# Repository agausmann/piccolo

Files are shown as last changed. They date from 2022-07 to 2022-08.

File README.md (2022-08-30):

# piccolo

A Raspberry Pi Pico clone with a USB-C port.

It's _\[current year\]_. Micro-USB is old news. But board designers are, for
some reason, still using it. I dunno, it might be a little cheaper/simpler.
Maybe you don't _technically_ need USB-C anway if you're not using USB 3.0.
But, in my experience, USB-C is just so much better; there is hardly any
reason to not use it.

## License

In the spirit of the original Pico design:

These design files are made available openly, with no limitations.

Permission to use, copy, modify, and/or distribute this design for
any purpose with or without fee is hereby granted.

THE DESIGN IS PROVIDED "AS IS" AND THE AUTHOR DISCLAIMS ALL WARRANTIES
WITH REGARD TO THIS DESIGN INCLUDING ALL IMPLIED WARRANTIES OF
MERCHANTABILITY AND FITNESS. IN NO EVENT SHALL THE AUTHOR BE LIABLE
FOR ANY SPECIAL, DIRECT, INDIRECT, OR CONSEQUENTIAL DAMAGES OR ANY
DAMAGES WHATSOEVER RESULTING FROM LOSS OF USE, DATA OR PROFITS, WHETHER
IN AN ACTION OF CONTRACT, NEGLIGENCE OR OTHER TORTIOUS ACTION, ARISING
OUT OF OR IN CONNECTION WITH THE USE OR PERFORMANCE OF THIS DESIGN.

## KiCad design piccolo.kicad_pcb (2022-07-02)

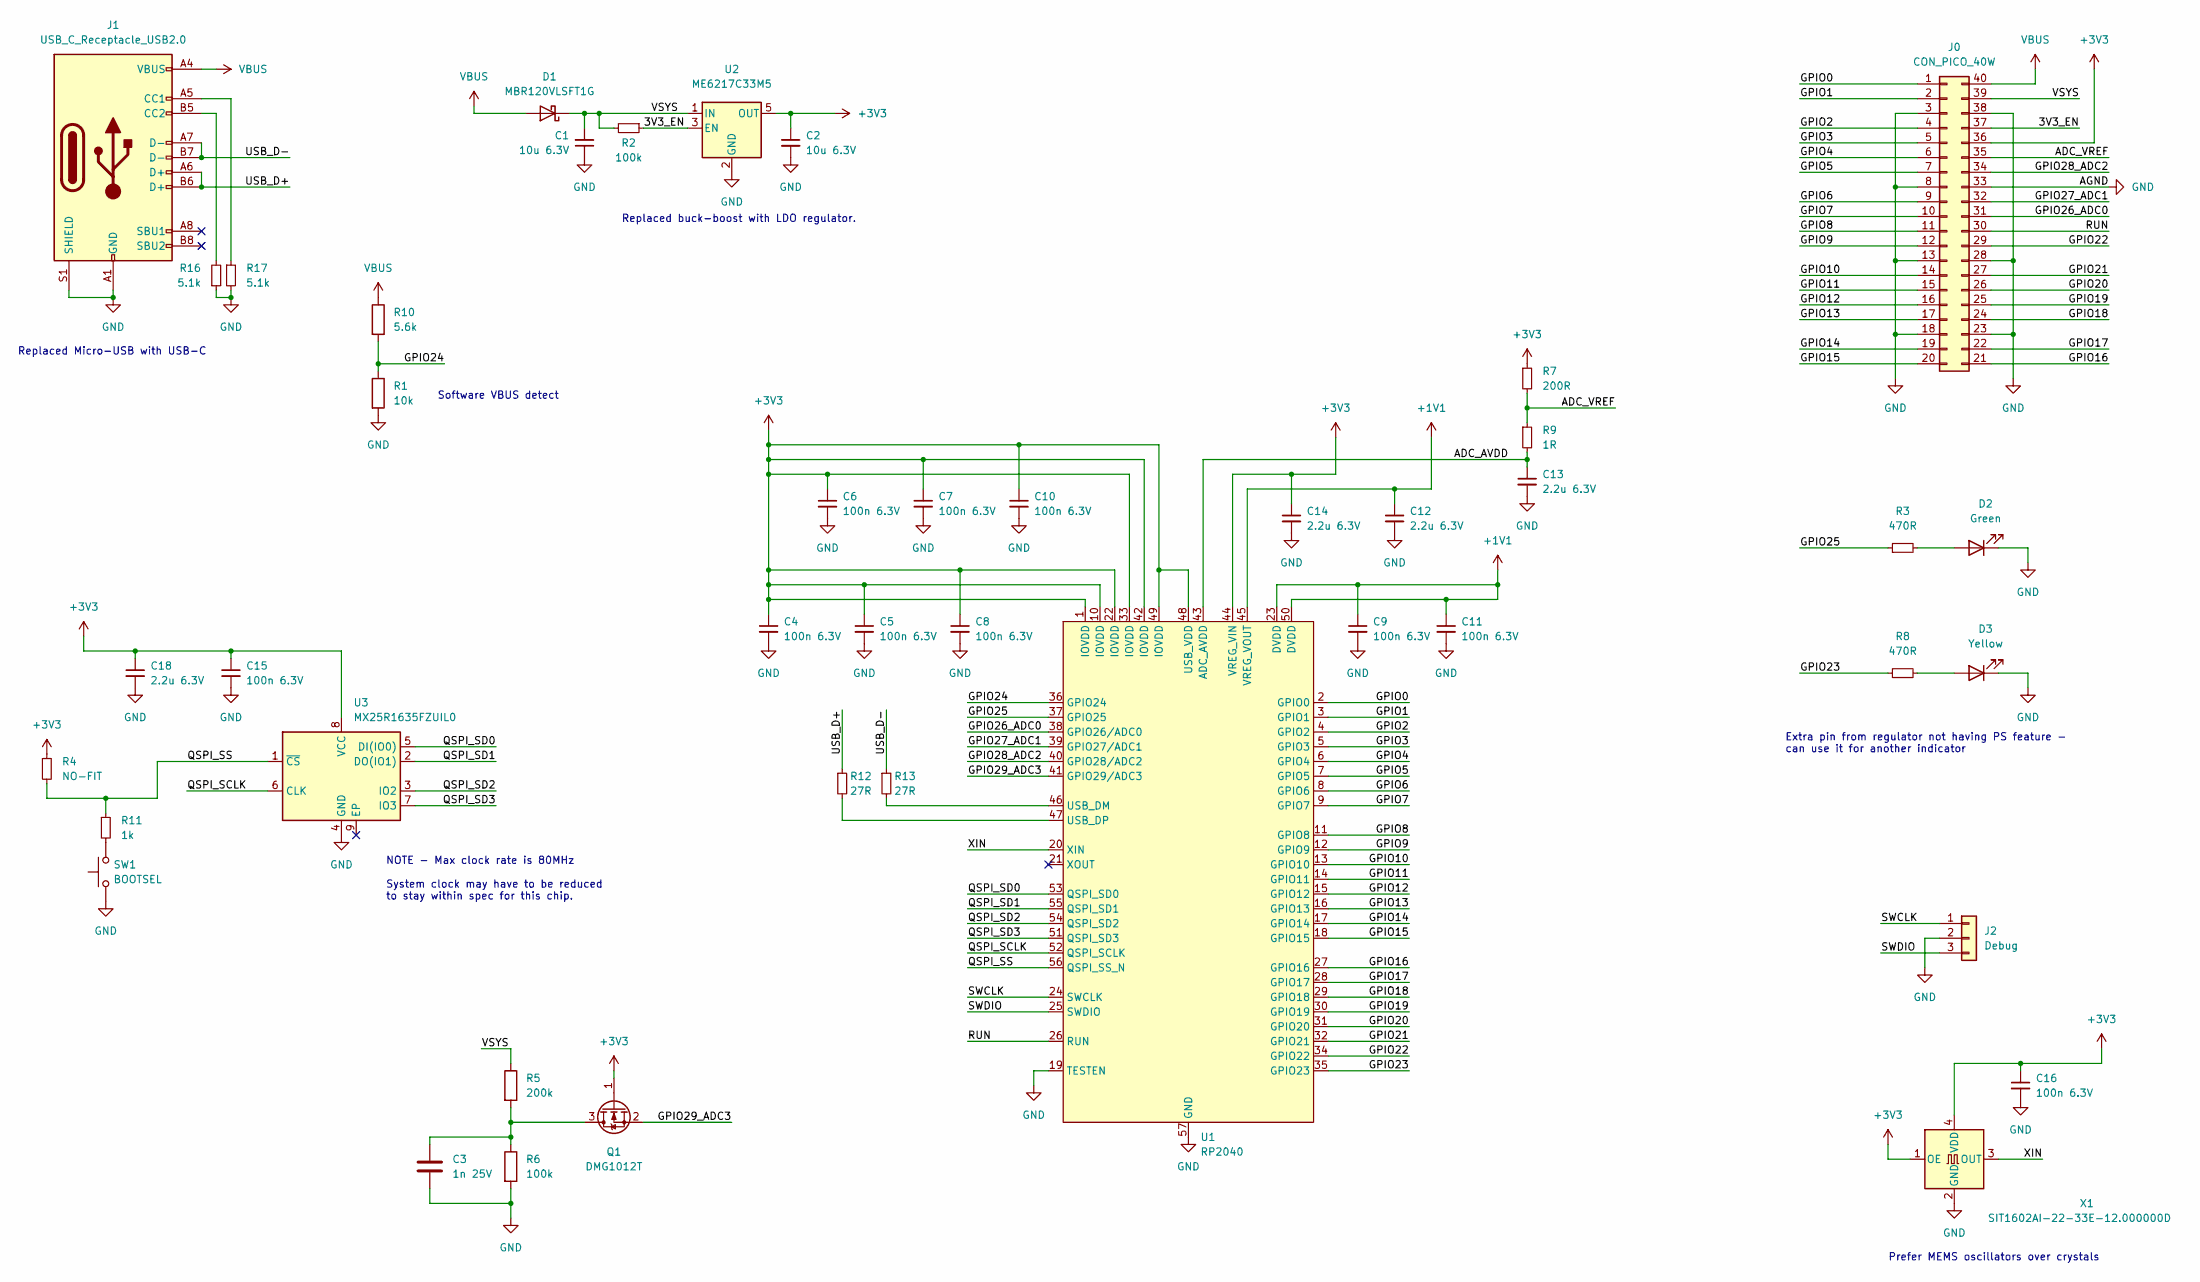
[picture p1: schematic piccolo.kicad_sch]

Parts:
C1, C2: 10u 6.3V; C_0805_2012Metric; LCSC C440198
C3: 1n 25V; C_0402_1005Metric; LCSC C66942
C4, C5, C6, C7, C8, C9, C10, C11, C15, C16: 100n 6.3V; C_0201_0603Metric; LCSC C160831
C12, C13, C14, C18: 2.2u 6.3V; C_0402_1005Metric; LCSC C12530
D1: MBR120VLSFT1G; D_SOD-123F; LCSC C123070
D2: Green; LED_0603_1608Metric; LCSC C72043
D3: Yellow; LED_0603_1608Metric; LCSC C72043
J0: CON_PICO_40W; RaspberryPi_Pico_OutlineAndPads
J1: USB_C_Receptacle_USB2.0; USB_C_Receptacle_HRO_TYPE-C-31-M-12; LCSC C165948
J2: Debug; PinHeader_1x03_P2.54mm_Vertical
Q1: DMG1012T; SOT-523; LCSC C2830301
R1: 10k; R_0402_1005Metric; LCSC C25744
R2, R6: 100k; R_0402_1005Metric; LCSC C25741
R3, R8: 470R; R_0402_1005Metric; LCSC C25117
R4: NO-FIT; R_0402_1005Metric
R5: 200k; R_0402_1005Metric; LCSC C25764
R7: 200R; R_0603_1608Metric; LCSC C25087
R9: 1R; R_0402_1005Metric; LCSC C25086
R10: 5.6k; R_0402_1005Metric; LCSC C25908
R11: 1k; R_0402_1005Metric; LCSC C11702
R12, R13: 27R; R_0201_0603Metric; LCSC C25100
R16, R17: 5.1k; R_0402_1005Metric; LCSC C25905
SW1: BOOTSEL; SW_Push_1P1T_NO_Vertical_Wuerth_434133025816
U1: RP2040; RP2040_QFN-56-1EP_7x7mm_P0.4mm_EP3.2x3.2mm_ThermalVias; LCSC C2040
U2: ME6217C33M5; SOT-23-5; LCSC C427602
U3: MX25R1635FZUIL0; USON-8-1EP_3x2mm_P0.5mm_EP0.2x1.6mm; LCSC C152595
X1: SIT1602AI-22-33E-12.000000D; SiT1602xx-2_3.2x2.5mm; LCSC C29752

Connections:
+1V1: C9.1, C11.1, C12.1, U1.23 (DVDD), U1.45 (VREG_VOUT), U1.50 (DVDD)
+3V3: C2.1, C4.1, C5.1, C6.1, C7.1, C8.1, C10.1, C14.1, C15.1, C16.1, C18.1, J0.36, Q1.1 (G), R4.1, R7.1, U1.1 (IOVDD), U1.10 (IOVDD), U1.22 (IOVDD), U1.33 (IOVDD), U1.42 (IOVDD), U1.44 (VREG_VIN), U1.48 (USB_VDD), U1.49 (IOVDD), U2.5 (OUT), U3.8 (VCC), X1.1 (OE), X1.4 (VDD)
/3V3_EN: J0.37, R2.1, U2.3 (EN)
/ADC_AVDD: C13.1, R9.2, U1.43 (ADC_AVDD)
/ADC_VREF: J0.35, R7.2, R9.1
/GPIO0: J0.1, U1.2 (GPIO0)
/GPIO1: J0.2, U1.3 (GPIO1)
/GPIO2: J0.4, U1.4 (GPIO2)
/GPIO3: J0.5, U1.5 (GPIO3)
/GPIO4: J0.6, U1.6 (GPIO4)
/GPIO5: J0.7, U1.7 (GPIO5)
/GPIO6: J0.9, U1.8 (GPIO6)
/GPIO7: J0.10, U1.9 (GPIO7)
/GPIO8: J0.11, U1.11 (GPIO8)
/GPIO9: J0.12, U1.12 (GPIO9)
/GPIO10: J0.14, U1.13 (GPIO10)
/GPIO11: J0.15, U1.14 (GPIO11)
/GPIO12: J0.16, U1.15 (GPIO12)
/GPIO13: J0.17, U1.16 (GPIO13)
/GPIO14: J0.19, U1.17 (GPIO14)
/GPIO15: J0.20, U1.18 (GPIO15)
/GPIO16: J0.21, U1.27 (GPIO16)
/GPIO17: J0.22, U1.28 (GPIO17)
/GPIO18: J0.24, U1.29 (GPIO18)
/GPIO19: J0.25, U1.30 (GPIO19)
/GPIO20: J0.26, U1.31 (GPIO20)
/GPIO21: J0.27, U1.32 (GPIO21)
/GPIO22: J0.29, U1.34 (GPIO22)
/GPIO23: R8.1, U1.35 (GPIO23)
/GPIO24: R1.1, R10.2, U1.36 (GPIO24)
/GPIO25: R3.1, U1.37 (GPIO25)
/GPIO26_ADC0: J0.31, U1.38 (GPIO26/ADC0)
/GPIO27_ADC1: J0.32, U1.39 (GPIO27/ADC1)
/GPIO28_ADC2: J0.34, U1.40 (GPIO28/ADC2)
/GPIO29_ADC3: Q1.2 (S), U1.41 (GPIO29/ADC3)
/QSPI_SCLK: U1.52 (QSPI_SCLK), U3.6 (CLK)
/QSPI_SD0: U1.53 (QSPI_SD0), U3.5 (DI(IO0))
/QSPI_SD1: U1.55 (QSPI_SD1), U3.2 (DO(IO1))
/QSPI_SD2: U1.54 (QSPI_SD2), U3.3 (IO2)
/QSPI_SD3: U1.51 (QSPI_SD3), U3.7 (IO3)
/QSPI_SS: R4.2, R11.1, U1.56 (QSPI_SS_N), U3.1 (~CS)
/RUN: J0.30, U1.26 (RUN)
/SWCLK: J2.1, U1.24 (SWCLK)
/SWDIO: J2.3, U1.25 (SWDIO)
/USB_D+: J1.A6 (D+), J1.B6 (D+), R12.1
/USB_D-: J1.A7 (D-), J1.B7 (D-), R13.1
/VSYS: C1.2, D1.1 (K), J0.39, R2.2, R5.1, U2.1 (IN)
/XIN: U1.20 (XIN), X1.3 (OUT)
GND: C1.1, C2.2, C3.2, C4.2, C5.2, C6.2, C7.2, C8.2, C9.2, C10.2, C11.2, C12.2, C13.2, C14.2, C15.2, C16.2, C18.2, D2.1 (K), D3.1 (K), J0.3, J0.8, J0.13, J0.18, J0.23, J0.28, J0.33, J0.38, J1.A1 (GND), J1.A12 (GND), J1.B1 (GND), J1.B12 (GND), J1.S1 (SHIELD), J2.2, R1.2, R6.2, R16.1, R17.2, SW1.1, U1.19 (TESTEN), U1.57 (GND), U2.2 (GND), U3.4 (GND), X1.2 (GND)
unnamed: C3.1, Q1.3 (D), R5.2, R6.1
unnamed: D2.2 (A), R3.2
unnamed: J1.A5 (CC1), R17.1
unnamed: J1.B5 (CC2), R16.2
unnamed: D3.2 (A), R8.2
unnamed: R11.2, SW1.2
unnamed: R12.2, U1.47 (USB_DP)
unnamed: R13.2, U1.46 (USB_DM)
VBUS: D1.2 (A), J0.40, J1.A4 (VBUS), J1.A9 (VBUS), J1.B4 (VBUS), J1.B9 (VBUS), R10.1

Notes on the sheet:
Replaced buck-boost with LDO regulator.
Prefer MEMS oscillators over crystals
Replaced Micro-USB with USB-C
Extra pin from regulator not having PS feature - can use it for another indicator
Software VBUS detect
NOTE - Max clock rate is 80MHz System clock may have to be reduced to stay within spec for this chip.

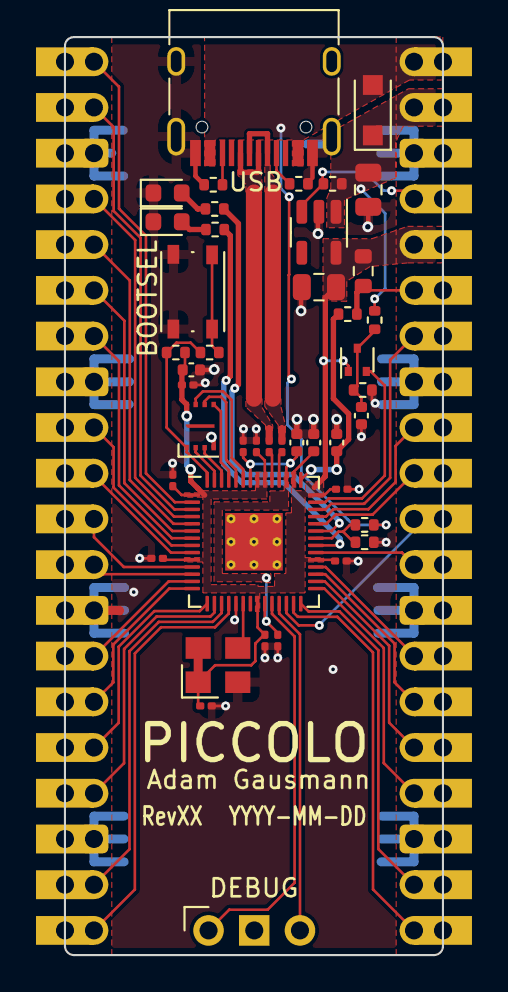
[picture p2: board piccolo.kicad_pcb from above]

Board: 2 copper layers, 21.0 x 51.0 mm, 44 parts (0 on the bottom side), 58 nets.

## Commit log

2022-06-27 Port schematic and very roughly position components
    [piccolo.kicad_pcb, piccolo.kicad_sch]
2022-07-02 Initial PCB design
    [piccolo.kicad_pcb, piccolo.kicad_sch]
2022-07-02 Fill out BOM
    [piccolo.kicad_sch]
